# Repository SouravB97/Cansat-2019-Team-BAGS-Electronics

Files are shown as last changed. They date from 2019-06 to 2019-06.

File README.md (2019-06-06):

# Cansat-2019-Team-BAGS-Electronics
Technical resources pertaining to the cansat created by Team BAGS in June 2019

The cansat contains 3 independant systems.

Section A is responsible for the overall telemetry and processing. It is fitted into the payload and has several I/O devices, including the zigbee radio which communicates with the ground station.

Section B is the camera module. It contains the camera as well as the equipment needed to stabilise it, which ensures that the camera points to one direction with respect to the earth's magnetic field, even if the cansat overall rotates continuosly.

Section C is the container module. It houses the container while the cansat is in the rocket, and releases it at an altitude of 450m as specified in the mission guidelines.

The ground station is reponsible for receiving the telemetry data from the cansat. It uses this data to generate a csv file, sensor data graphs, gps plots, and a tilt animation of the deployed cansat.

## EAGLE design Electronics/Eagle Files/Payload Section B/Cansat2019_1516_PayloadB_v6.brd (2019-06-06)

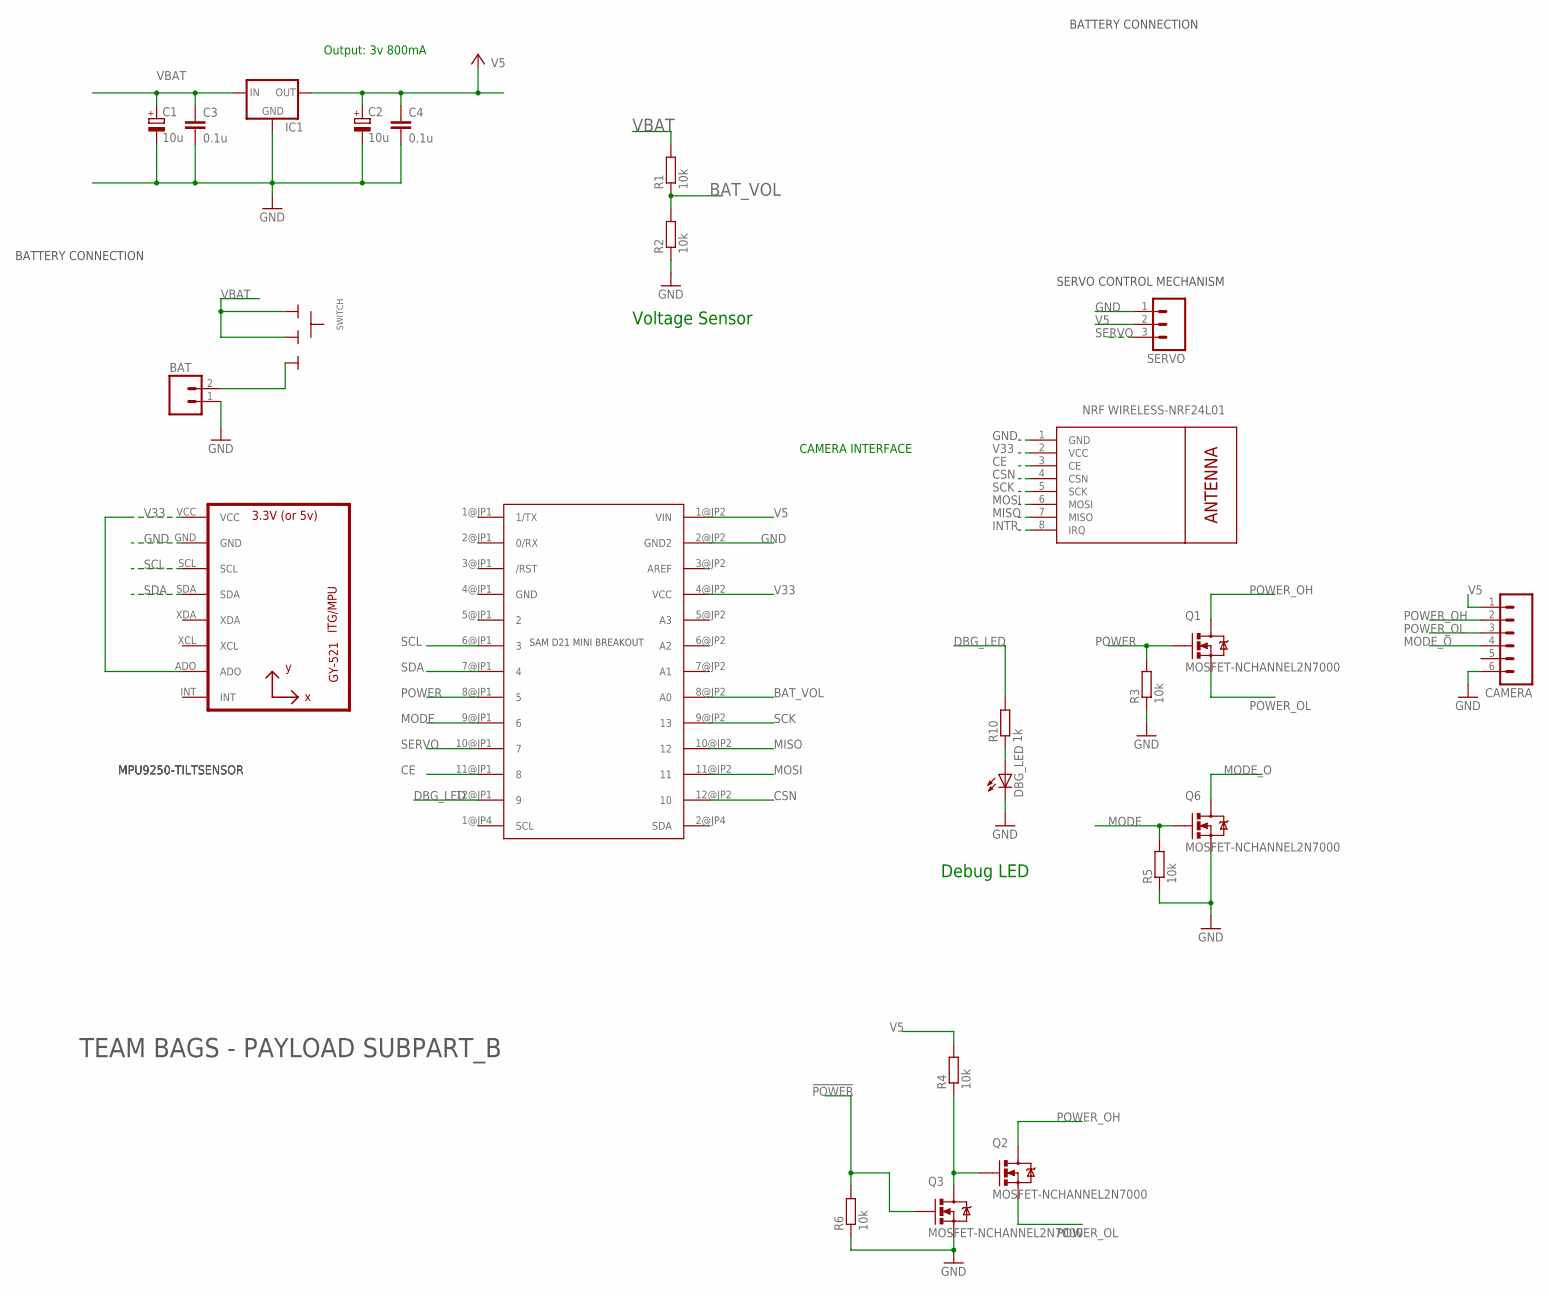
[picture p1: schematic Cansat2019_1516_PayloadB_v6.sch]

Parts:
BAT: M02; 02P
C1, C2: 10u; E2-4
C3, C4: 0.1u; C025-025X050
CAMERA: M06; 06P
DBG_LED: LED3MM
IC1: V_REG_78XX-TO-220; TO-220-ALT
MPU: GY-521MPU6050; GY-521
NRF: WIRELESS-NRF24L01
Q1, Q2, Q3, Q6: MOSFET-NCHANNEL2N7000; TO-92
R1, R2, R3, R4, R5, R6: 10k; 0204/7
R10: 1k; 0204/7
SERVO: M03; 03P
SWITCH: SLIDESWITCH-BIG; BIGSWITCH
U$2: SAM_D21_MINI_BREAKOUT; JP1_SPARKFUN-SAMD21-MINI-BREAKOUT-V10

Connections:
!POWER: Q3.2 (G), R6.2
AREF: U$2.3@JP2 (AREF)
BAT_VOL: R1.1, R2.2, U$2.8@JP2 (A0)
CE: NRF.3 (CE), U$2.11@JP1 (8)
CSN: NRF.4 (CSN), U$2.12@JP2 (10)
DBG_LED: R10.2, U$2.12@JP1 (9)
GND: BAT.1, C1.-, C2.-, C3.2, C4.2, CAMERA.6, DBG_LED.K (C), IC1.GND, MPU.GND, NRF.1 (GND), Q3.1 (S), Q6.1 (S), R2.1, R3.1, R5.1, R6.1, SERVO.1, U$2.2@JP2 (GND2), U$2.4@JP1 (GND)
INTR: NRF.8 (IRQ)
MISO: NRF.7 (MISO), U$2.10@JP2 (12)
MODE: Q6.2 (G), R5.2, U$2.9@JP1 (6)
MODE_O: CAMERA.4, Q6.3 (D)
MOSI: NRF.6 (MOSI), U$2.11@JP2 (11)
unnamed: BAT.2, SWITCH.3
unnamed: Q2.2 (G), Q3.3 (D), R4.1
unnamed: DBG_LED.A, R10.1
POWER: Q1.2 (G), R3.2, U$2.8@JP1 (5)
POWER_OH: CAMERA.2, Q1.3 (D), Q2.3 (D)
POWER_OL: CAMERA.3, Q1.1 (S), Q2.1 (S)
SCK: NRF.5 (SCK), U$2.9@JP2 (13)
SCL: MPU.SCL, U$2.6@JP1 (3)
SDA: MPU.SDA, U$2.7@JP1 (4)
SERVO: SERVO.3, U$2.10@JP1 (7)
V5: C2.+, C4.1, CAMERA.1, IC1.OUT, R4.2, SERVO.2, U$2.1@JP2 (VIN)
V33: MPU.ADO, MPU.VCC, NRF.2 (VCC), U$2.4@JP2 (VCC)
VBAT: C1.+, C3.1, IC1.IN, R1.2, SWITCH.1, SWITCH.2

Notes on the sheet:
Output: 3v 800mA
MPU9250-TILTSENSOR
BATTERY CONNECTION
SERVO CONTROL MECHANISM
CAMERA INTERFACE
TEAM BAGS - PAYLOAD SUBPART_B
Voltage Sensor
Debug LED

Board: 2 copper layers, 25 parts (17 on the bottom side), 23 nets, no tracks yet.

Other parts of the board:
U$1: SG90_TOP

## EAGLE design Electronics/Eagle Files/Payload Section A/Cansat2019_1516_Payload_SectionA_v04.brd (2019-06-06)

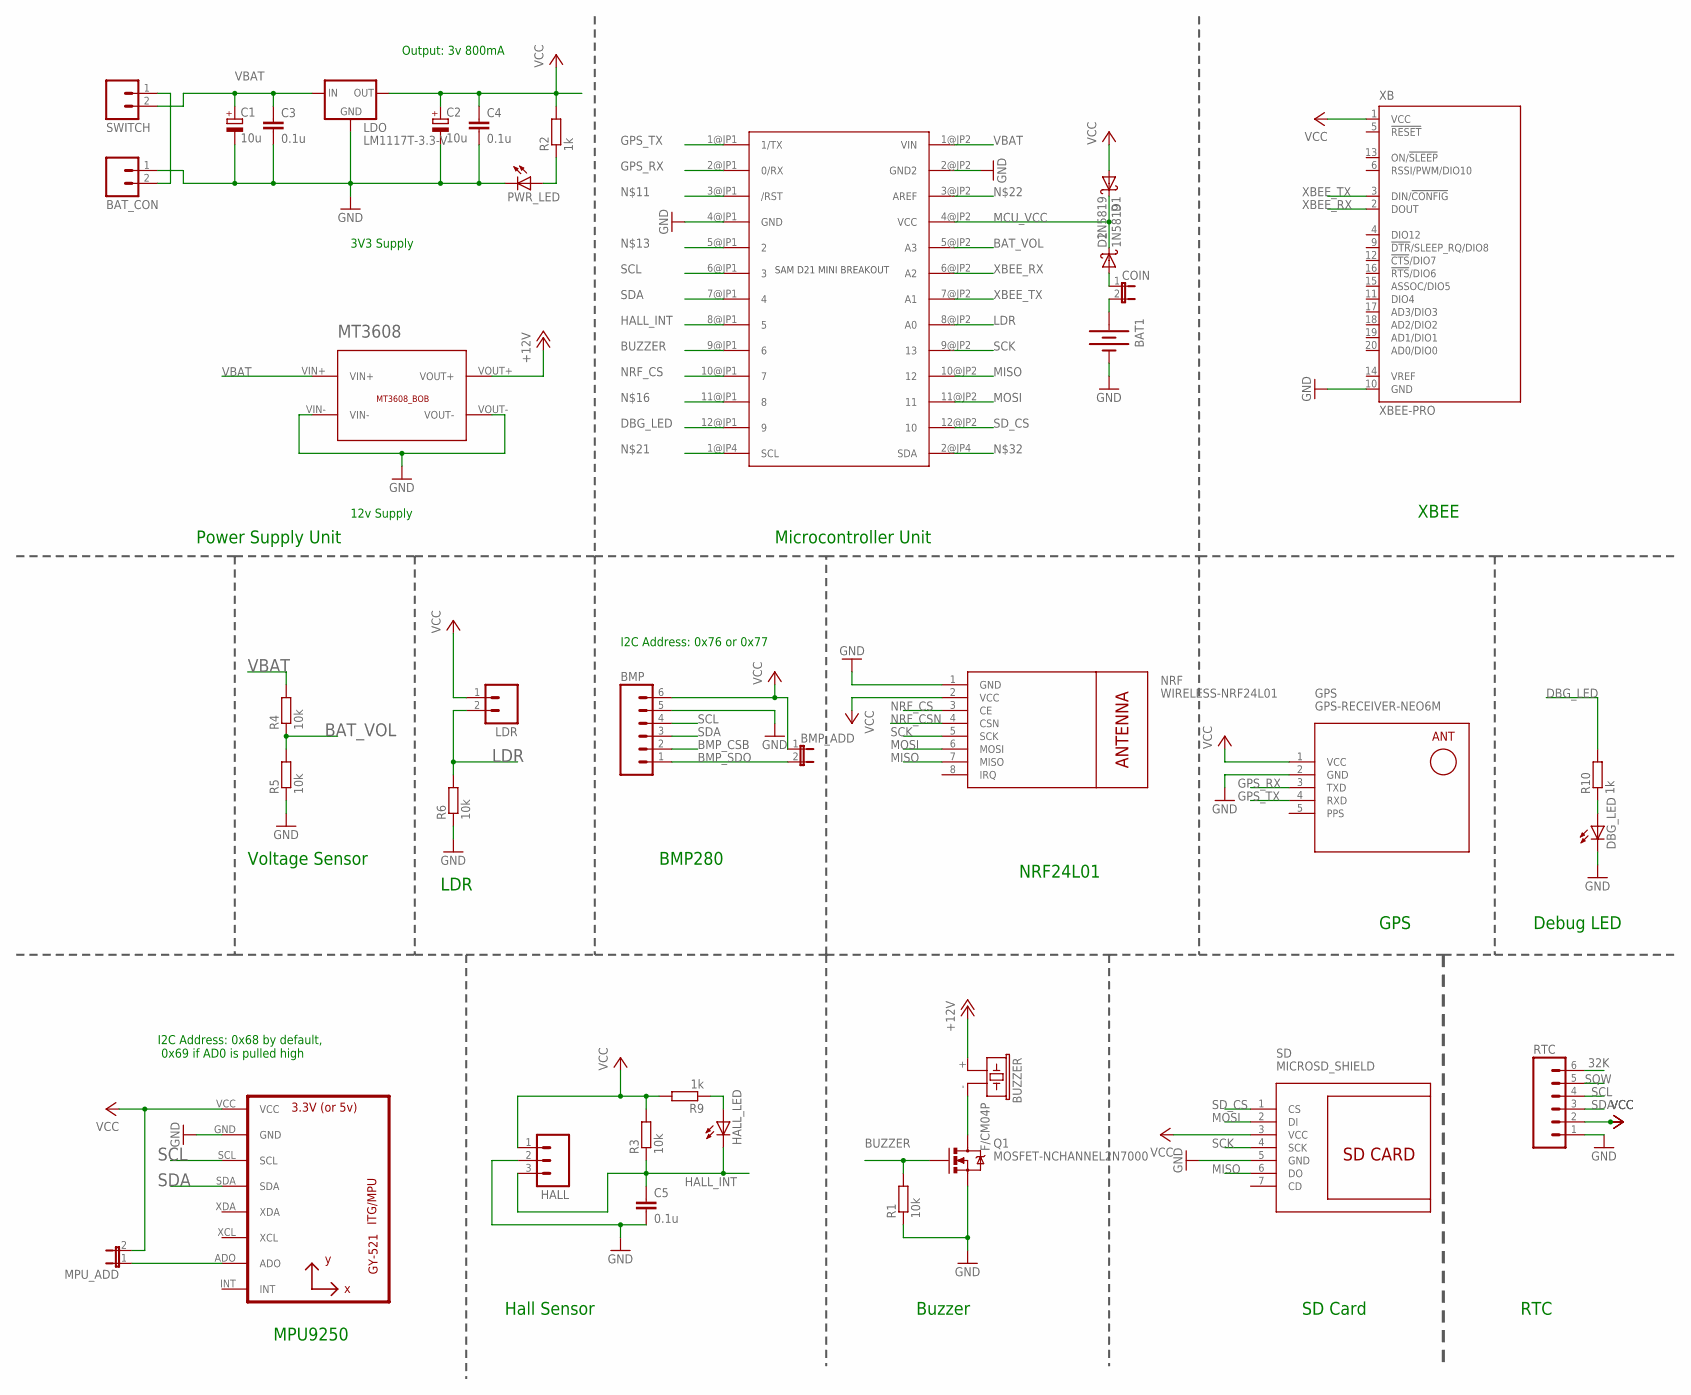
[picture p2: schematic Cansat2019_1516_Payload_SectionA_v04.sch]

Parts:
BAT1: BATTERY20PTH; BATTCOM_20MM_PTH
BAT_CON: M02; 02P
BMP: M06; 06P
BMP_ADD: JUMPER-2PTH; 1X02
BUZZER: F/CM04P
C1, C2: 10u; E2,5-6
C3, C4, C5: 0.1u; C025-025X050
COIN: JUMPER-2PTH; 1X02
D1, D2: 1N5819; DO41-10
DBG_LED: LED3MM
GPS: GPS-RECEIVER-NEO6M
HALL: M03; 03P
HALL_LED: LED3MM
LDO: LM1117T-3.3-V; TO220V
LDR: M02; 02P
MPU: GY-521MPU6050; GY-521
MPU_ADD: JUMPER-2PTH; 1X02
MT3608: MT3608_BOB
NRF: WIRELESS-NRF24L01
PWR_LED: LED3MM
Q1: MOSFET-NCHANNEL2N7000; TO-92
R1, R3, R4, R5, R6: 10k; 0204/7
R2, R9, R10: 1k; 0204/7
RTC: M06; 06P
SAMD: SAM_D21_MINI_BREAKOUT; JP1_SPARKFUN-SAMD21-MINI-BREAKOUT-V10
SD: MICROSD_SHIELD
SWITCH: M02; 02P
XB: XBEE-PRO

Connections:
32K: RTC.6
+12V: BUZZER.+ (1), MT3608.VOUT+
BAT_VOL: R4.1, R5.2, SAMD.5@JP2 (A3)
BMP_CSB: BMP.2
BMP_SDO: BMP.1, BMP_ADD.2
BUZZER: Q1.2 (G), R1.2, SAMD.9@JP1 (6)
DBG_LED: R10.2, SAMD.12@JP1 (9)
GND: BAT1.2 (-), BAT_CON.1, BMP.5, C1.-, C2.-, C3.2, C4.2, C5.2, DBG_LED.K (C), GPS.2 (GND), HALL.2, LDO.1 (GND), MPU.GND, MT3608.VIN-, MT3608.VOUT-, NRF.1 (GND), PWR_LED.K (C), Q1.1 (S), R1.1, R5.1, R6.1, RTC.1, SAMD.2@JP2 (GND2), SAMD.4@JP1 (GND), SD.5 (GND), XB.10 (GND)
GPS_RX: GPS.3 (TXD), SAMD.2@JP1 (0/RX)
GPS_TX: GPS.4 (RXD), SAMD.1@JP1 (1/TX)
HALL_INT: C5.1, HALL.3, HALL_LED.K (C), R3.1, SAMD.8@JP1 (5)
LDR: LDR.2, R6.2, SAMD.8@JP2 (A0)
MCU_VCC: D1.C, D2.C, SAMD.4@JP2 (VCC)
MISO: NRF.7 (MISO), SAMD.10@JP2 (12), SD.6 (DO)
MOSI: NRF.6 (MOSI), SAMD.11@JP2 (11), SD.2 (DI)
unnamed: BUZZER.- (2), Q1.3 (D)
unnamed: COIN.1, D2.A
unnamed: PWR_LED.A, R2.1
unnamed: BAT1.1 (+), COIN.2
unnamed: BAT_CON.2, SWITCH.1
unnamed: MPU.ADO, MPU_ADD.1
unnamed: HALL_LED.A, R9.1
unnamed: DBG_LED.A, R10.1
NRF_CS: NRF.3 (CE), SAMD.10@JP1 (7)
NRF_CSN: NRF.4 (CSN)
PPS: GPS.5 (PPS)
SCK: NRF.5 (SCK), SAMD.9@JP2 (13), SD.4 (SCK)
SCL: BMP.4, MPU.SCL, RTC.4, SAMD.6@JP1 (3)
SDA: BMP.3, MPU.SDA, RTC.3, SAMD.7@JP1 (4)
SD_CS: SAMD.12@JP2 (10), SD.1 (CS)
SQW: RTC.5
VBAT: C1.+, C3.1, LDO.3 (IN), MT3608.VIN+, R4.2, SAMD.1@JP2 (VIN), SWITCH.2
VCC: BMP.6, BMP_ADD.1, C2.+, C4.1, D1.A, GPS.1 (VCC), HALL.1, LDO.2 (OUT), LDR.1, MPU.VCC, MPU_ADD.2, NRF.2 (VCC), R2.2, R3.2, R9.2, RTC.2, SD.3 (VCC), XB.1 (VCC)
XBEE_RX: SAMD.6@JP2 (A2), XB.2 (DOUT)
XBEE_TX: SAMD.7@JP2 (A1), XB.3 (DIN/!CONFIG)

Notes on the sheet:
Power Supply Unit
3V3 Supply
12v Supply
Output: 3v 800mA
Microcontroller Unit
Buzzer
Voltage Sensor
BMP280
GPS
XBEE
MPU9250
SD Card
NRF24L01
LDR
Hall Sensor
I2C Address: 0x76 or 0x77
I2C Address: 0x68 by default, 0x69 if AD0 is pulled high
RTC
Debug LED

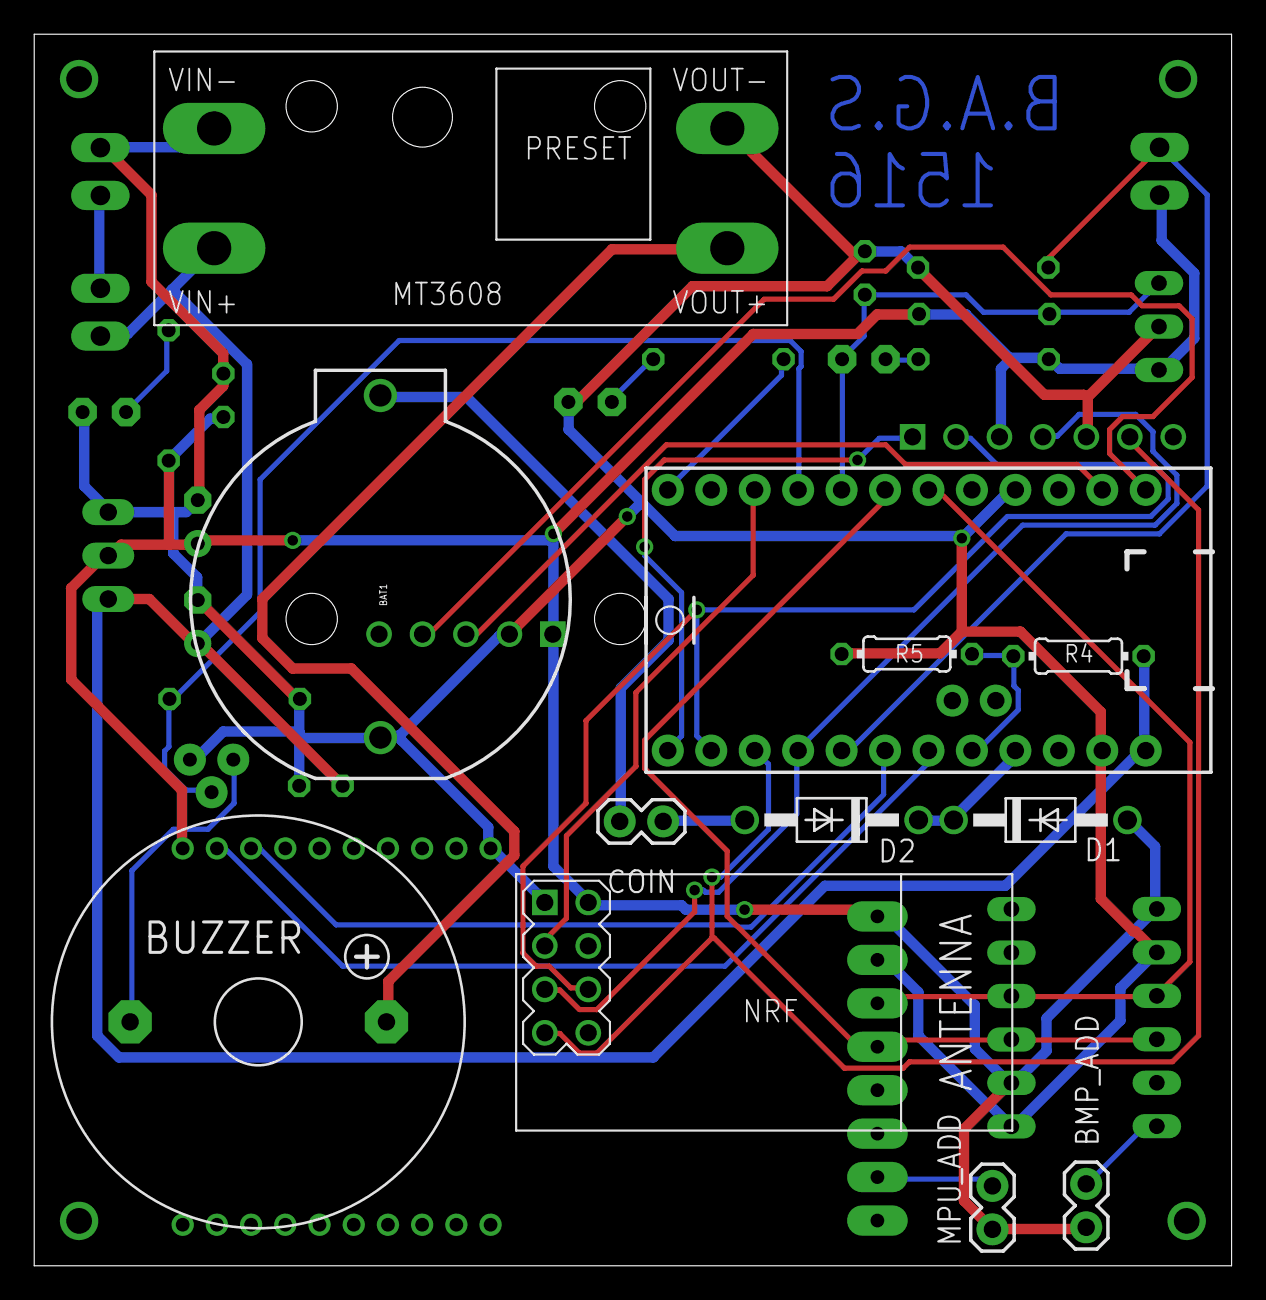
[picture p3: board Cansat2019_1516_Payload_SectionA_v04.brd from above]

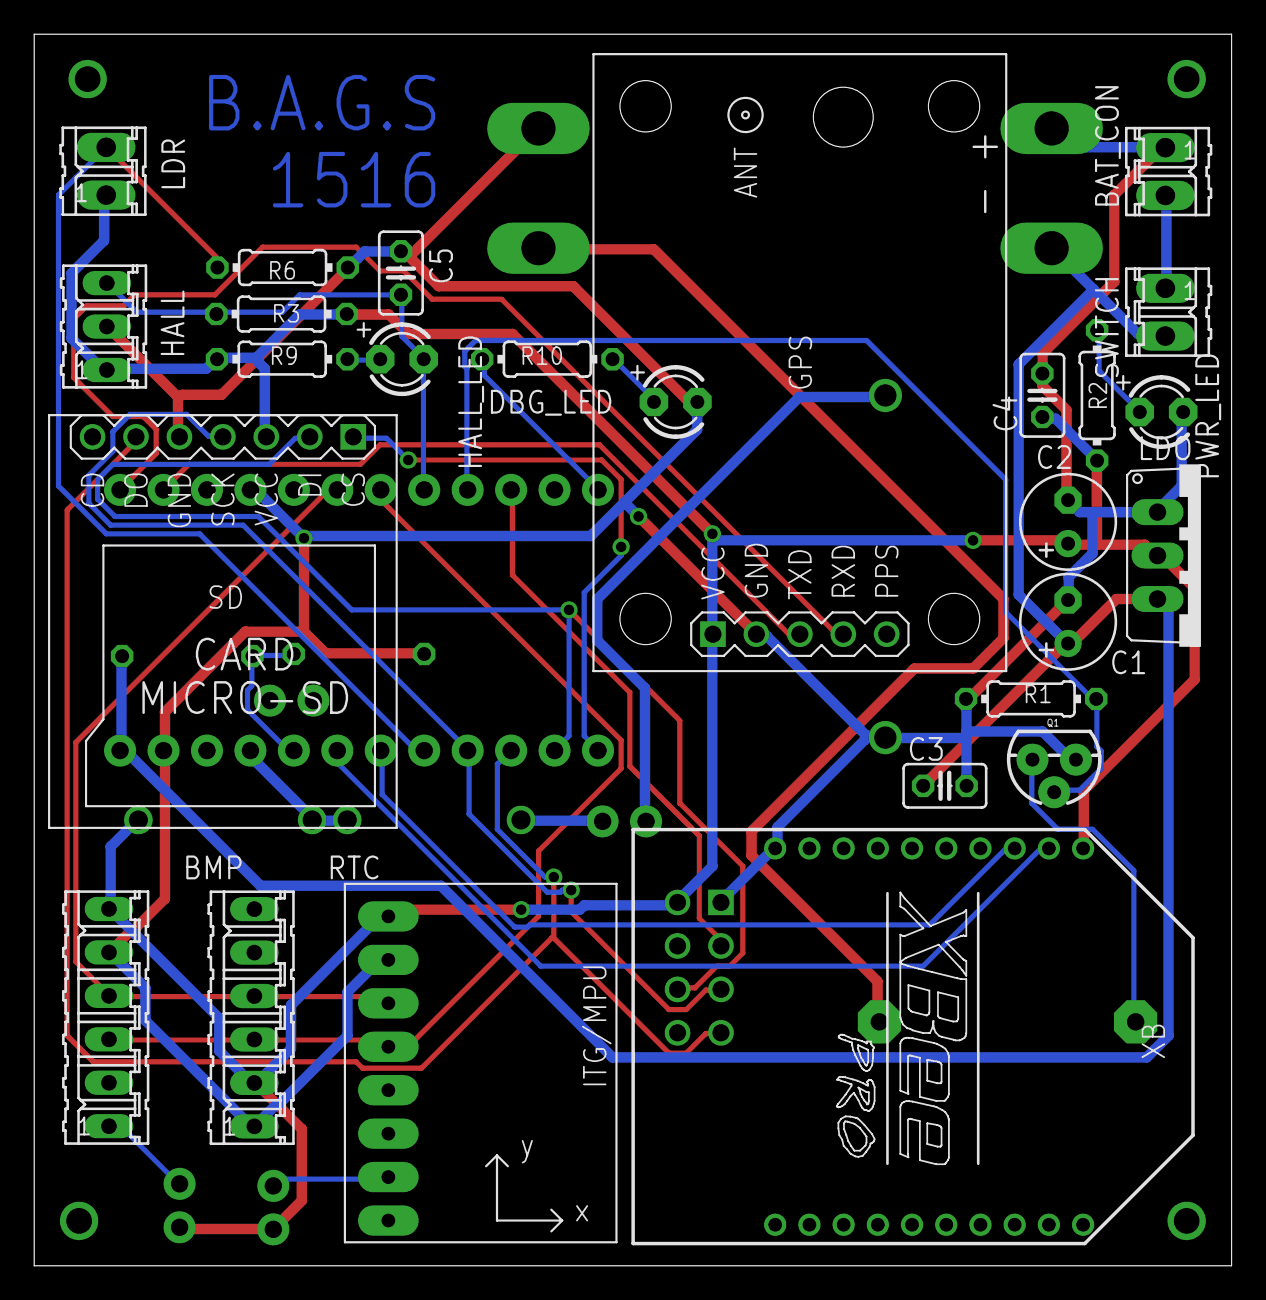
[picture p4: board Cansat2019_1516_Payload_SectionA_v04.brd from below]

Board: 2 copper layers, 70.0 x 72.0 mm, 38 parts (26 on the bottom side), 30 nets.

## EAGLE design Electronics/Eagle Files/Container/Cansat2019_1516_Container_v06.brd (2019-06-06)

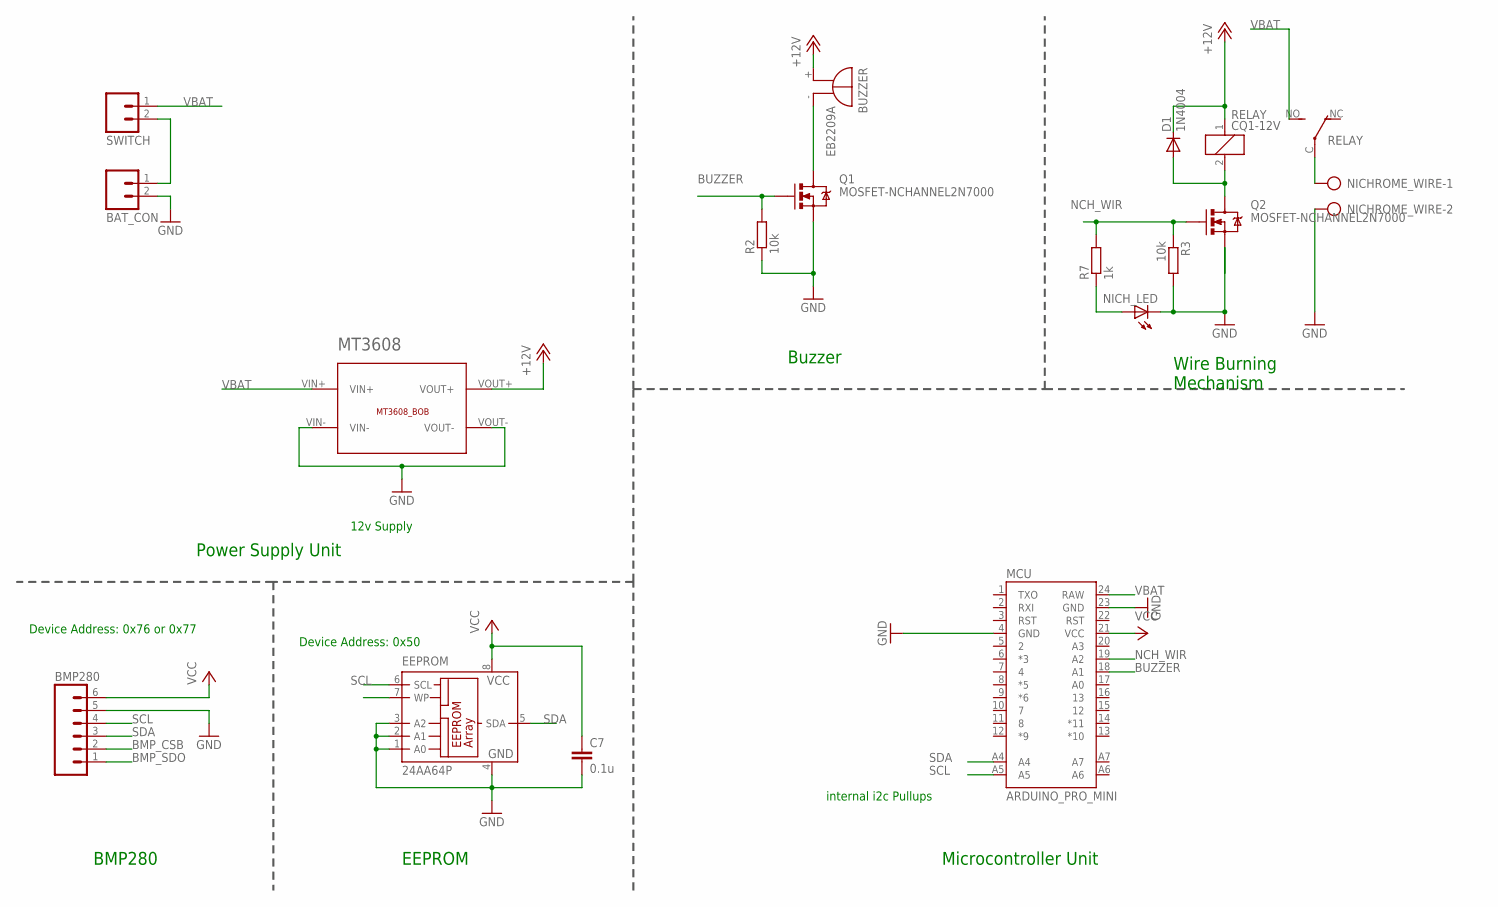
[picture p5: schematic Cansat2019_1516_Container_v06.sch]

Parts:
BAT_CON: M02; 02P
BMP280: M06; 06P
BUZZER: EB2209A
C7: 0.1u; C025-025X050
D1: 1N4004; DO41-10
EEPROM: 24AA64P; DIL8
MCU: ARDUINO_PRO_MINI
MT3608: MT3608_BOB
NICHROME_WIRE: AK500/2-H
NICH_LED: LED3MM
Q1, Q2: MOSFET-NCHANNEL2N7000; TO-92
R2, R3: 10k; 0204/7
R7: 1k; 0204/7
RELAY: CQ1-12V; CQ1
SWITCH: M02; 02P

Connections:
+12V: BUZZER.+, D1.C, MT3608.VOUT+, RELAY.1
BMP_CSB: BMP280.2
BMP_SDO: BMP280.1
BUZZER: MCU.18 (A1), Q1.2 (G), R2.2
GND: BAT_CON.2, BMP280.5, C7.2, EEPROM.1 (A0), EEPROM.2 (A1), EEPROM.3 (A2), EEPROM.4 (GND), MCU.4 (GND), MCU.23 (GND), MT3608.VIN-, MT3608.VOUT-, NICHROME_WIRE.2, NICH_LED.K (C), Q1.1 (S), Q2.1 (S), R2.1, R3.2
unnamed: BUZZER.-, Q1.3 (D)
unnamed: NICHROME_WIRE.1, RELAY.C
unnamed: NICH_LED.A, R7.1
unnamed: BAT_CON.1, SWITCH.2
unnamed: D1.A, Q2.3 (D), RELAY.2
NCH_WIR: MCU.19 (A2), Q2.2 (G), R3.1, R7.2
SCL: BMP280.4, EEPROM.6 (SCL), MCU.A5
SDA: BMP280.3, EEPROM.5 (SDA), MCU.A4
VBAT: MCU.24 (RAW), MT3608.VIN+, RELAY.NO (S), SWITCH.1
VCC: BMP280.6, C7.1, EEPROM.8 (VCC), MCU.21 (VCC)

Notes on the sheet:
Power Supply Unit
Buzzer
Wire Burning Mechanism
Microcontroller Unit
12v Supply
BMP280
Device Address: 0x50
EEPROM
Device Address: 0x76 or 0x77
internal i2c Pullups

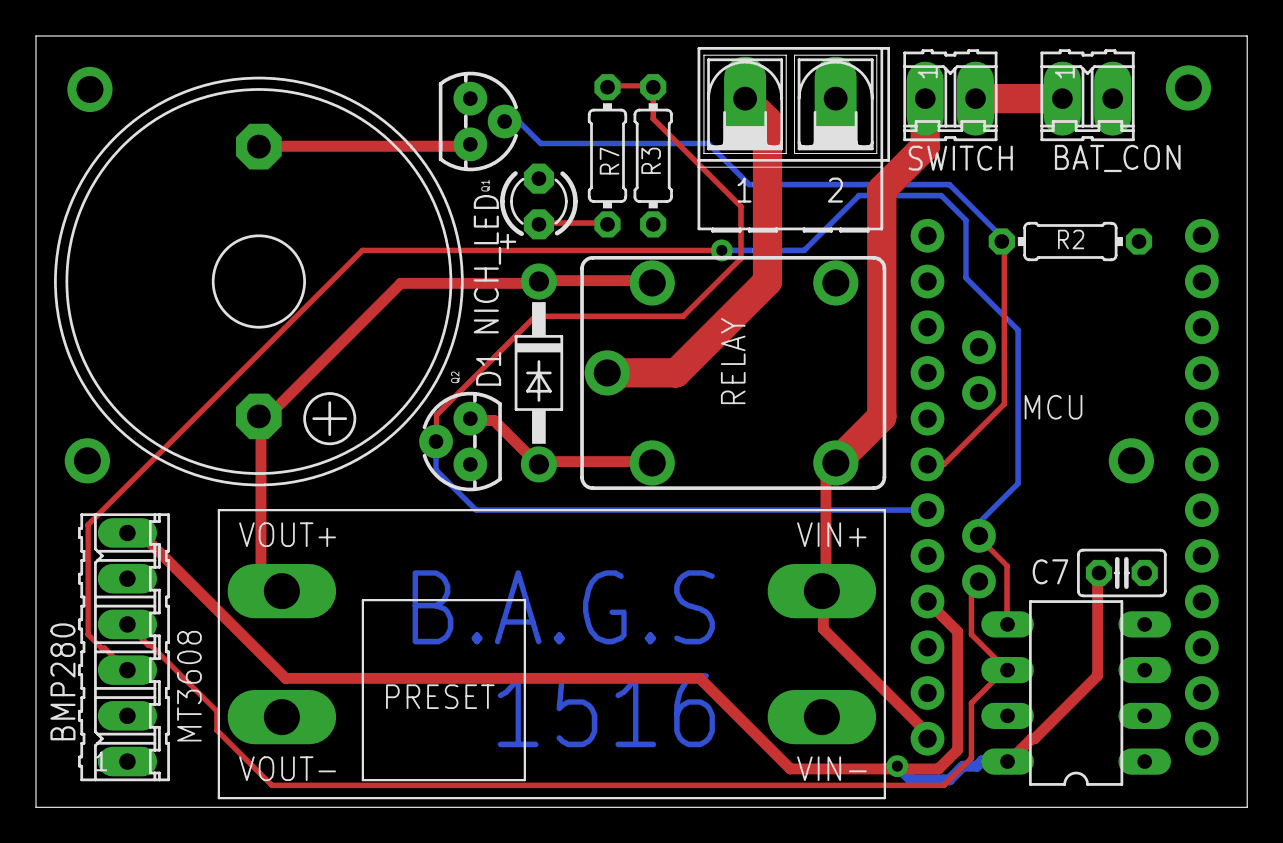
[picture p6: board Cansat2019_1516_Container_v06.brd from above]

Board: 2 copper layers, 67.3 x 42.9 mm, 17 parts (0 on the bottom side), 13 nets.

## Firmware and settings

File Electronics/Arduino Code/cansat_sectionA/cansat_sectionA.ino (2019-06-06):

#include "pindef.h"

enum secB_command {
  START_REC, STOP_REC, START_STAB, STOP_STAB, START_DIR_TX, STOP_DIR_TX
};

//Serial1 is defined by default
Uart Serial2 (&sercom4, UART1_RX, UART1_TX, SERCOM_RX_PAD_1, UART_TX_PAD_0);
TwoWire Wire1(&sercom2, SDA, SCL);
//SPI is defined by default.
//SPIClass SPI1(&sercom1, MISO, SCK, MOSI, SPI_PAD_0_SCK_1, SERCOM_RX_PAD_3);

Adafruit_BMP280 bmp;
MPU6050 mpu6050(Wire1);
TinyGPSPlus gps;
RTCZero rtc;
RH_NRF24 nrf24;
packet dataPacket(TEAM_ID);

File packetFile;		//file handle for packet.csv
File missionLog;		//file handle for missin.log

volatile bool telemetry = false;	//flag which masks telemetry
volatile int packet_count = 0;
volatile uint8_t state = boot;

bool video_recording  = false;
bool secb_stabilising = false;
bool cansat_calibrated = false;

const int BAT_VALUE = 3300;

const int n_threads = 4;	//Number of timer threads in telemetry loop
const uint16_t thread_wait_time[] = {100, 250, 500, 1000};	//Time after which each thread gets called
uint32_t thread_start_time[n_threads] = {0};


void setup(){
	pinMode(POW_WAKEUP, INPUT);
	analogReadResolution(12);
	delay(300);
	while(isPowerOn()){//if(!digitalRead(POW_WAKEUP)){	//power button off or disconnect
		delay(300);	//or spend time sleeping
	}
	initCansat();
}

void loop(){
	switch(state){
		case BOOT:{
			//wait for power on
			//for some reason, calling analogRead on the SAMD21 doesnt let digitalRead be called. 
			//It always returns 0.
			if(isPowerOn()){//if(!digitalRead(POW_WAKEUP)){	//power button off or disconnect
				delay(300);	//or spend time sleeping
			}
			else{
				state = TELEMETRY;
				telemetry = true;
				enableTimerInterrupts();
				setNrfTxFlag();
				dataPacket.software_state = idle;
				#ifdef SER_DEBUG	
					Serial.println("State changed to : " + String(state));
				#endif
				#ifdef LOG_MISSION
					logEvent("State changed to : " + String(state));
				#endif	
			}
		}	break;
		
		case INIT:{		
			NVIC_SystemReset();      // processor software reset	
			telemetry = false;
			disableTimerInterrupts();
			disableMPUInterrupts();
			zigbee.flush();	//clear radio buffer
			zigbee.end();
			if(isPowerOn()){//if(!digitalRead(POW_WAKEUP)){	//power button off or disconnect
				delay(300);	//or spend time sleeping
			}
			else{
				//Power button pushed
				//delay(1000); //wait for everything to stabilise
				NVIC_SystemReset();      // processor software reset	
				//initCansat();
				//initVolatileSensors();	
				//calibCansat();
				state = TELEMETRY;
				telemetry = true;
				enableTimerInterrupts();
				setNrfTxFlag();
				enableMPUInterrupts();
				//dataPacket.software_state = idle;
				#ifdef SER_DEBUG	
					Serial.println("State changed to : " + String(state));
				#endif
				#ifdef LOG_MISSION
					logEvent("State changed to : " + String(state));
				#endif
			}	
		} break;
		
		case TELEMETRY:{
				
			if(isPowerOn()){//if(!digitalRead(POW_WAKEUP)){	//Check if battery disconnected
				state = INIT;
				break;
			}
			
			for(int thread = 0; thread < n_threads; thread++){
				if(millis() - thread_start_time[thread] >= thread_wait_time[thread]){
					switch(thread){
						case 0:	//Runs ever 100 ms
							
							//already called regardless of state
							// #ifdef SER_DEBUG
								// console(Serial);
							// #endif			
							// console(zigbee);
							
							break;
						case 1:	//Runs every 250 ms
							
							dataPacket.voltage = getBatteryVoltage();
							
							break;
						case 2:	//Runs every 500 ms
							
							dataPacket.mission_time = getMissionTime();
							dataPacket.roll = getRoll();
							dataPacket.pitch = getPitch();
							updateBMP();
							dataPacket.altitude = getAltitude();
							dataPacket.pressure = getPressure();
							dataPacket.temperature = getTemperature();
							
							dataPacket.software_state = processSoftwareState();				
							switch(dataPacket.software_state){
								case boot:
									break;
								case idle:
									break;
								case launch_detect:
									break;
								case deploy:
									break;
								case payload_release:{
									//start recording
									if(!video_recording){
										if(nrfTransmitWithAck(START_REC))	//if it times out, dont worry, we'll get em in the next iteration
											video_recording = true;
									}
									//start stabilising Section B
									if(!secb_stabilising){
										if(nrfTransmitWithAck(START_STAB))
											secb_stabilising = true;
									}
									//toggle TX LED
									//digitalWrite(PIN_LED_TXL, !digitalRead(PIN_LED_TXL));
								}
									break;
								case landed:{
						
									//stop camera recording
									for(int i = 0; i<5; ){	// give up trying to send command after 5 tries
										//stop camera recording
										if(video_recording)
											if(nrfTransmitWithAck(STOP_REC)){
												video_recording = false;
												break;
											}
											else{
												i++;
												delay(300);
											}
									}
									//stop camera stabilisation
									for(int i = 0; i<5; ){	// give up trying to send command after 5 tries
										//stop sec_b stabilising
										if(secb_stabilising)
											if(nrfTransmitWithAck(STOP_STAB)){
												secb_stabilising = false;
												break;
											}
											else{
												i++;
												delay(300);
											}
									}
									
									delay(1500);	//wait for last couple of packets to transmit this state.
										
									telemetry = false;
									disableTimerInterrupts();
									state = RECOVERY;	//telemetry done
									#ifdef SER_DEBUG	
										Serial.println("State changed to : " + String(state));
									#endif
									#ifdef LOG_MISSION
										logEvent("State changed to : " + String(state));
									#endif						
								}
									break;
								default:;
							}
												
							
							break;
						case 3:{	//Runs every 1000 ms
							
							updateGps();
							dataPacket.blade_spin_rate = getBladeSpinRate();	//call it every second
							if (telemetry) safe_println(&packetFile, dataPacket.toString()/* + String(getYaw())*/);//write packet to SD card.

						}
							break;
						default:;
					}
					thread_start_time[thread] = millis();
				}
			}
			//Code runs as fast as possible.
			
			// get bonus direction from section B
			if(getNrfRxFlag())
				if (nrf24.available())
						dataPacket.bonus_direction = nrfReceiveData();
										
		}break;
		
		case RECOVERY:{
			//camera recording, stabilisation and telemetry already turned off.
			static int wait_time = 500;	//Buzzer blink toggle time
			if(isPowerOn()){	//Check if recovery crew switched cansat off
				delay(300);
				if(isPowerOn()){	//Check if recovery crew actually switched cansat off
					state = BOOT;
					cansat_calibrated = false;
					break;	//return to state BOOT
				}
			}
			static uint32_t start_time = 0;
			if((millis() - start_time) >= wait_time){
				digitalWrite(DBG_LED, !digitalRead(DBG_LED));
				digitalWrite(BUZZER, !digitalRead(BUZZER));
				
				//already called regardless of state
				// #ifdef SER_DEBUG
					// console(Serial);
				// #endif			
					// console(zigbee);
				start_time = millis();
			}
		}break;
		
		default:;
	}
	//print state every 2 seconds
	// static uint32_t loop_tstart = millis();
	// if(millis() - loop_tstart >= 1000){
		// Serial.print("State : " + String(state));
		// Serial.print("\tpow wakeup < 1000 ?: " + String((isPowerOn())));
		// Serial.println("\tpow wakeup val: " + String(analogRead(POW_WAKEUP)));
		// loop_tstart = millis();
	// }
	#ifdef SER_DEBUG
		console(Serial);
	#endif			
	console(zigbee);
	
}//</loop>

void TC5_Handler (void) {
	//YOUR CODE HERE	
	
	if(telemetry){
		//digitalWrite(DBG_LED, !digitalRead(DBG_LED));
		digitalWrite(DBG_LED, HIGH);
		dataPacket.packet_count = ++packet_count;
		String telemetry = dataPacket.toString();
		#ifdef SER_DEBUG
			//Serial.println(telemetry);
			dataPacket.display();
		#endif
		zigbee.println(telemetry);
		digitalWrite(DBG_LED, LOW);
	}
	// END OF YOUR CODE
	TC5->COUNT32.INTFLAG.bit.MC0 = 1; //Interrupt serviced, so clear the flag.
}


//Include all the code that is stored in the MCU memory
void initCansat(){
	telemetry = false;	//flag which masks telemetry
	packet_count = 0;		
	state = BOOT;
	
	rtc.begin();
	//initLowPower();
	
	#ifdef SER_DEBUG
		//USBDevice.init();
		//USBDevice.attach();
		Serial.begin(115200);
		//while(!Serial);
	#endif 
		
	gps_uart.begin(9600);
	zigbee.begin(9600);
	Wire1.begin();
	
	pinMode(POW_WAKEUP, INPUT);
	pinMode(DBG_LED, OUTPUT);
	pinMode(LED_BUILTIN, OUTPUT);
	pinMode(BUZZER, OUTPUT);
	pinMode(PIN_LED_TXL, OUTPUT);
	
	digitalWrite(DBG_LED, LOW);
	digitalWrite(LED_BUILTIN, LOW);
	analogReadResolution(12);
	
	initSerial();
	initSD();	
	createFiles();
	initBatteryVoltage();
	initHall();
	initLDR();
	initMpu();
	initBmp();	
	initNrf();
	
	resetMissionTime();
	//CONFIGURE TIMERS AND IRQ
	tc5Configure(1000);	//interrupt every second
	disableTimerInterrupts();
				
	#ifdef SER_DEBUG
		Serial.println(F("Cansat initialisation complete."));
	#endif	
	#ifdef LOG_MISSION
		logEvent(F("Cansat initialisation complete."));
	#endif		
}

/*
	Include initialisation for volatile peripherals
*/	
/*
void initVolatileSensors(){
	
	// zigbee.begin(9600);
	initSD();
	disableMPUInterrupts();
		initBmp();
		initMpu();
	enableMPUInterrupts();
	initNrf();
	#ifdef SER_DEBUG
		Serial.println(F("Volatile sensor initialisation complete."));
	#endif	
	#ifdef LOG_MISSION
		logEvent(F("Volatile sensor initialisation complete."));
	#endif		
}
*/
void initVolatileSensors(){
	telemetry = false;	//flag which masks telemetry
	//packet_count = 0;		
	//state = BOOT;
	
	//rtc.begin();
	//initLowPower();
	
	#ifdef SER_DEBUG
		//USBDevice.init();
		//USBDevice.attach();
		//Serial.begin(115200);
		//while(!Serial);
	#endif
		
	gps_uart.begin(9600);
	zigbee.begin(9600);
	//Wire1.begin();
	
	//pinMode(POW_WAKEUP, INPUT);
	//pinMode(DBG_LED, OUTPUT);
	//pinMode(LED_BUILTIN, OUTPUT);
	
	digitalWrite(DBG_LED, LOW);
	digitalWrite(LED_BUILTIN, LOW);
	//analogReadResolution(12);
	
	initSerial();
	initSD();	
	//createFiles();
	initBatteryVoltage();
	initHall();
	initLDR();
	initBmp();
	initMpu();
	initNrf();
	
	//resetMissionTime();
	//CONFIGURE TIMERS AND IRQ
	//tc5Configure(1000);	//interrupt every second
	disableTimerInterrupts();
				
	#ifdef SER_DEBUG
		Serial.println(F("Cansat initialisation complete."));
	#endif	
	#ifdef LOG_MISSION
		logEvent(F("Cansat initialisation complete."));
	#endif			
}


void calibCansat(){
	
	callibrateMPU();
	callibrateBMP();
	callibrateAmbientBrightness();
	resetHall();
	resetMissionTime();
	packet_count = 0;	//reset packet count
		
	cansat_calibrated = true;
	#ifdef SER_DEBUG
		Serial.println(F("Cansat calibration complete."));
	#endif
	#ifdef LOG_MISSION
		logEvent(F("Cansat calibration complete."));
	#endif
}

/*
	Processes sensor data and decides which op_state cansat is in. 
	*/
op_state processSoftwareState(){
	static op_state state = boot;
	
	//These flags ensure that a next state is attained only when its previous state was already attained.
	static bool idled = false;
	static bool launch_detected = false;
	static bool deployed = false;
	static bool payload_released = false;	
	
	//These flags stop the state from coming back to previous state.
	static bool idle_crossed = false;
	static bool launch_detect_crossed = false;
	static bool	deploy_crossed = false;
	static bool	payload_release_crossed = false;
	
		
	bool cansatReleased = droppedFromRocket();	//get light change data from LDR
	
	if(cansat_calibrated == false){
		state = boot;
	}
	else{
		//Rocket on the launchpad
		if(
			(dataPacket.altitude < 5) 				&&
			//(abs(dataPacket.roll)  < 1) 			&&
			//(abs(dataPacket.pitch)  < 1) 			&&
			//(mpu6050.accY < -0.5)							&&
			//(dataPacket.blade_spin_rate < 1)	&&
			(cansatReleased == false)				&&
			
			//no <prev_state reached> check as it is the first state
			(idle_crossed == false)
			){
				idled = true;
				state = idle;		
			}
			
		//rocket has started to ascend, till it reaches maximum point
		else if(
			(dataPacket.altitude > 1) 				&&
			//(abs(dataPacket.roll)  < 1) 			&&
			//(abs(dataPacket.pitch)  < 1) 			&&
			((mpu6050.accY < -0.7))							&&
			(dataPacket.blade_spin_rate < 1)	&&
			(cansatReleased == false)					&&
			
			(idled == true)										&&
			(launch_detect_crossed == false)
			){
				idle_crossed = true;
				launch_detected = true;
				state = launch_detect;
			}
				
		//cansat container has detached from the rocket and is falling with the parachute
		else if(
			(dataPacket.altitude > 450) 				&&
			//(abs(dataPacket.roll)  < 1) 			&&
			//(abs(dataPacket.pitch)  < 1) 			&&
			(mpu6050.accY < -1.2)							&&
			(dataPacket.blade_spin_rate < 1)	&&
			(cansatReleased == true)				&&
			
			(launch_detected == true)				&&
			(deploy_crossed == false)		
			){
				launch_detect_crossed = true;
				deployed = true;
				state = deploy;
			}
		
		//container has released the payload, and it is falling with autogyro
		else if(
			(dataPacket.altitude < 500) 			&&
			//(abs(dataPacket.roll)  < 1) 			&&
			//(abs(dataPacket.pitch)  < 1) 			&&
			//(mpu6050.accY < -0.5)							&&
			//(dataPacket.blade_spin_rate > 0)	&&
			(cansatReleased == true)						&&
				
			(deployed == true)									&&	
			(payload_release_crossed == false)
			){
				deploy_crossed = true;
				payload_released = true;
				state = payload_release;			
			}
			
		//payload has landed on the ground, and has stopped moving
		else if(
			(dataPacket.altitude < 50) 				&&
			//(abs(dataPacket.roll)  < 1) 			&&
			//(abs(dataPacket.pitch)  < 1) 			&&
			(abs(mpu6050.accY) < 1.2)							&&
			(dataPacket.blade_spin_rate < 1)	&&
			(cansatReleased == true)					&&
			
			(payload_released == true)
			//no landed_crossed check as it is the last state
			){
				payload_release_crossed = true;
				state = landed;	
			}
			
		//default: return whatver state was previously computed
	}
	
	//also, toggle tx_led every time state is changed.
	static op_state prev_state = boot;
	if(state != prev_state){
		digitalWrite(PIN_LED_TXL, !digitalRead(PIN_LED_TXL));
		prev_state = state;
	}

	return state;
}

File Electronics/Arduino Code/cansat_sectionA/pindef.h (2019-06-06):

#include <Arduino.h>   // required before wiring_private.h
#include <Wire.h>
#include <SPI.h>
#include <SD.h>
#include <RTCZero.h>
#include <MadgwickAHRS.h>
#include <TinyGPS++.h>
#include <RH_NRF24.h>

#include "wiring_private.h" // pinPeripheral() function
#include "Adafruit_BMP280.h"
#include "MPU6050_tockn.h"
#include "packet.h"

#define UART0_RX 0	//defined by default Serial1
#define UART0_TX 1

#define UART1_RX A2 //Serial2
#define UART1_TX A1

#define SDA 4 //Wire1
#define SCL 3

#define MOSI 11 //default SPI
#define MISO 12
#define SCK  13

#define NRF_CE			8		//NRF only works with these pins.
#define NRF_CSN			10	//So they are hardwired. This is just for the programmer.

#define BAT_VOL			A3
#define HALL_INT		5
#define SD_SELECT		7
#define POW_WAKEUP	A3	//8
#define LDR 				A0
#define BUZZER			6
#define DBG_LED			9

#define Serial			SerialUSB
#define gps_uart		Serial1
#define zigbee			Serial2

#define LOG_MISSION			//enable this to log mission events to SD card
#define SER_DEBUG				//enable this to get debug info in serial monitor
#define TEAM_ID 1516		//BAGS

#define BOOT				0		//reset
#define INIT				1		//Sensors initialised and ready for telemetry
#define TELEMETRY		2		//performing telemetry and related computation
#define RECOVERY		3		//waiting for recovery from crew

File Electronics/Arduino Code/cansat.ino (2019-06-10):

// libraries to be included
#include <BMP280_DEV.h>
#include <Wire.h>
#include <Eeprom24C04_16.h>
#include <EEPROM.h>

#define EEPROM_ADDRESS 0x50
#define BUZZER A1
#define RELAY A2
#define MATCH_TILL 3
#define MATCH_TILL_UNEVEN 5000
#define UPPER_ALT_BOUND 4
#define LOWER_ALT_BOUND 2
#define EEPROM_SIZE 8096
#define BUZZER_ACTIVATE_ALTITUDE 1
#define HEATTIME 2000
#define MINDIFFHEIGHT 1
#define ALTITUDE_TOLERANCE 2
#define ALTITUDE_ASCEND_TOLERANCE 0.5
#define SERDEBUG true

float altitude, altitude_const, altitude_init, alt_abs, altitude_final;
// altitude = gives the BMP280 recorded altitude
// altitude_const = locally defined atitude for checking
// altitude_init = altitude value initialized
// alt_abs = absolute altitude
// altitude_final = final static altitude
short int count, countUneven, iter;
// count = MATCH_TILL, check till the point we need to match the altitude
// countUneven = MATCH_TILL_UNEVEN, check iteration to match altitude static value
// iter = iteration point to start storing data
bool record, stat, pass, uneven, cfchecker, isrtimeout, checkIfInFlight, initial_fix, dual_checker;
// record = true if altitude greater than 10m
// stat = true when the initialisation is complete
// pass = alitude greater than UPPER_BOUND
// cfchecker = check if the container is released
// isrtimeout the EEPROM is recording
// checkIfInFlight = check if the initialization is midflight
// initial_fix =  helper variable for altitude checker at initialisation
// dual checker = helper variable for altitude checker at landing

byte tempStore[4]; // extra buffer for storing the EEPROM data
union {
    float fval;
    byte bval[4];
  } floatAsBytes;
union {
    short int ival;
    byte bval[2];
    } IntAsBytes;

// initialize BMP library
BMP280_DEV bmp280;
int counter;
static Eeprom24C04_16 eeprom(EEPROM_ADDRESS);

void setup() {
  Serial.begin(9600);
  initializePins();
  initializeSensors();
  initializeTimer();
  initializeVariables();
  checkWhereAreWe();
  digitalWrite(RELAY, HIGH);
  delay(HEATTIME);
  digitalWrite(RELAY, LOW);
}

void loop() {
//   #ifdef SERDEBUG
//    altitude = getAltitiude();
//    Serial.println("----------------");
//    Serial.println("Altitude Entered" + String(altitude)); 
//   #endif
   bmp280.getAltitude(altitude);
   //logMapper();
   if (!checkIfInFlight && !stat) {
    altitudechecker();
   }
   
   if (record) {
       recordData();
   } else {
       recordChecker();
   }
   
   passAlter();
   
   if (alt_abs <= UPPER_ALT_BOUND && alt_abs >= LOWER_ALT_BOUND && pass == true && cfchecker == false) {
        containerRelease();
        cfchecker = true;
   }
   
   containerReleaseFailCheck();
   
   if ((alt_abs <= BUZZER_ACTIVATE_ALTITUDE || uneven == true) && pass == true) {
       buzzerActivate();
   }

   if (pass) {
    unevenChecker();
   }
}

void initializePins() {
  pinMode(BUZZER, OUTPUT);
  pinMode(RELAY, OUTPUT);
  pinMode(LED_BUILTIN, OUTPUT);
  digitalWrite(RELAY, LOW);
  }

void initializeSensors() {
  // Code to initialize all sensors
  eeprom.initialize();
  // initiate BMP280_ addresses
  bmp280.begin(BMP280_I2C_ALT_ADDR);              // Default initialisation with alternative I2C address (0x76), place the BMP280 into SLEEP_MODE 
  bmp280.startNormalConversion();                 // Start BMP280 continuous conversion in NORMAL_MODE
  bmp280.setPresOversampling(OVERSAMPLING_X16);   // Setup the BMP280 to oversampling of X16
  bmp280.setIIRFilter(IIR_FILTER_16);  
}

void initializeTimer() {
  // Code to initialize timer at 1Hz
  cli();
  TCCR1A = 0; // set entire TCCR1A register to 0
  TCCR1B = 0; // same for TCCR1B
  TCNT1  = 0; //initialize counter value to 0
  // set compare match register for 1hz increments
  OCR1A = 7812; //(16*10^6) / (1*1024) - 1 (must be <65536)
  // turn on CTC mode
  // Set CS10 and CS12 bits for 1024 prescaler
  TCCR1B |= (1 << CS12) | (1 << CS10);  
  // enable timer compare interrupt
  TIMSK1 |= (1 << OCIE1A);
  sei();
}

void initializeVariables() {
  // variable setup
  count = MATCH_TILL;
  countUneven = MATCH_TILL_UNEVEN;
  iter = 0;
  record = false, stat = false, pass = false, uneven = false, cfchecker = false, isrtimeout = false, checkIfInFlight = false;
  initial_fix = true, dual_checker = true;
  counter = 1;
  }

void checkWhereAreWe() {
  byte status_val = EEPROM.read(EEPROM.length() - 1);
  if ((bool)status_val == true) {
    checkIfInFlight = true;
    
    floatAsBytes.bval[0] = EEPROM.read(EEPROM.length() - 2);
    floatAsBytes.bval[1] = EEPROM.read(EEPROM.length() - 3);
    floatAsBytes.bval[2] = EEPROM.read(EEPROM.length() - 4);
    floatAsBytes.bval[3] = EEPROM.read(EEPROM.length() - 5);
    float altitude_init = floatAsBytes.fval;
    
    byte value_of_alt_iter[2]; 
    IntAsBytes.bval[0] = EEPROM.read(EEPROM.length() - 6);
    IntAsBytes.bval[1] = EEPROM.read(EEPROM.length() - 7);
    iter = IntAsBytes.ival;
    
    pass = (bool)EEPROM.read(EEPROM.length() - 8);
    record = true;
    }
  else if ((bool)status_val == false){    
    
    counter = 0;
    
    }
  else {
    
    counter = 0;
    
    }
  }

void logMapper() {
  #ifdef SERDEBUG
  Serial.println("Enter Altitude: ");
  Serial.println("Current Flight Log: ");
  Serial.println("----------------------");
  Serial.println("Check in Flight: " + String(checkIfInFlight));
  Serial.println("Counter Value: " + String(count));
  Serial.println("Altitude Initialized: " + String(altitude_init));
  Serial.println("Is recording started: " + String(record));
  Serial.println("EEPROM Iteration: " + String(iter));
  Serial.println("Pass Status: " + String(pass));
  Serial.println("Container Release Condition: " + String(cfchecker));
  Serial.println("Altitude Final: " + String(altitude_final));
  #endif
  }

float getAltitiude() {
  logMapper();
  while(!Serial.available()) {
    }
  return Serial.parseFloat();
}

void altitudechecker() {
  if (altitude != 0 && initial_fix == true) {
    
    if (count == MATCH_TILL) {
      initial_fix = true;
      altitude_const = altitude;
      count = MATCH_TILL - 1;
    }
    
    else {
      if (count == 0) {
        altitude_init = altitude_const;
        stat = true;
        initial_fix = false;
        digitalWrite(LED_BUILTIN, HIGH);
        delay(100);
        digitalWrite(LED_BUILTIN, LOW);
        delay(100);
        digitalWrite(LED_BUILTIN, HIGH);
        delay(100);
        digitalWrite(LED_BUILTIN, LOW);
      }
      
      else if ((abs(altitude - altitude_const) <= ALTITUDE_TOLERANCE)) {
          count--;
        }
      
      else {
        if (initial_fix) {
          count = MATCH_TILL;
          stat = false;
        }
      }
    }
  }
}

void recordData() {
  alt_abs = altitude - altitude_init;
  
  if (isrtimeout) {
    
    eeWrite(alt_abs);
    isrtimeout = false;
    
  }
}

void recordChecker() {
  if ((stat) && (altitude - altitude_init) >= MINDIFFHEIGHT) {
    
    record = true;
  
  }
}
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

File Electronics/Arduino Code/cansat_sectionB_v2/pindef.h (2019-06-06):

#include <Arduino.h>   // required before wiring_private.h
#include <Wire.h>
#include <SPI.h>
#include <MadgwickAHRS.h>
#include <RH_NRF24.h>
#include <Servo.h>

#include "wiring_private.h" // pinPeripheral() function
#include "MPU9250_tockn.h"

#define SDA 4 //Wire1
#define SCL 3

#define KP 5
#define KI 0
#define KD 0

#define MOSI 11 //default SPI
#define MISO 12
#define SCK  13

#define NRF_CE			8		//NRF only works with these pins.
#define NRF_CSN			10	//So they are hardwired. This is just for the programmer.

#define BAT_VOL			A0
#define CAM_PWR			5
#define CAM_MODE		6
#define SERVO				7
#define DBG_LED			9

#define Serial		SerialUSB

#define SER_DEBUG		//enable this to get debug info in serial monitor

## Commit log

2019-06-06 Added all the files.
    [Cansat2019_1516_Container_v06.brd, Cansat2019_1516_Container_v06.sch, Cansat2019_1516_PayloadB_v6.brd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]
2019-06-06 Added GCS Software folder
    [Cansat2019_1516_Container_v06.brd, Cansat2019_1516_Container_v06.sch, Cansat2019_1516_PayloadB_v6.brd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]

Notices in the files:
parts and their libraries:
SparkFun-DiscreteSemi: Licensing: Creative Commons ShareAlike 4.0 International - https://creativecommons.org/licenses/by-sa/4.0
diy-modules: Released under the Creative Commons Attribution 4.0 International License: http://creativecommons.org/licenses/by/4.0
